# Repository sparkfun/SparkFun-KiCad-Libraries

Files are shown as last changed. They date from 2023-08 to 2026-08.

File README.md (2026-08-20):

SparkFun Electronics KiCad Libraries
====================================

This repository contains the SparkFun KiCad Libraries of commonly used parts. It is a cultivated combination of KiCad stock parts,  SparkFun-unique footprints, and open-source 3D models. The main branch is generally proven out but we apologize in advance if these libraries have errors. Please report any issues! We'll fix them quickly.

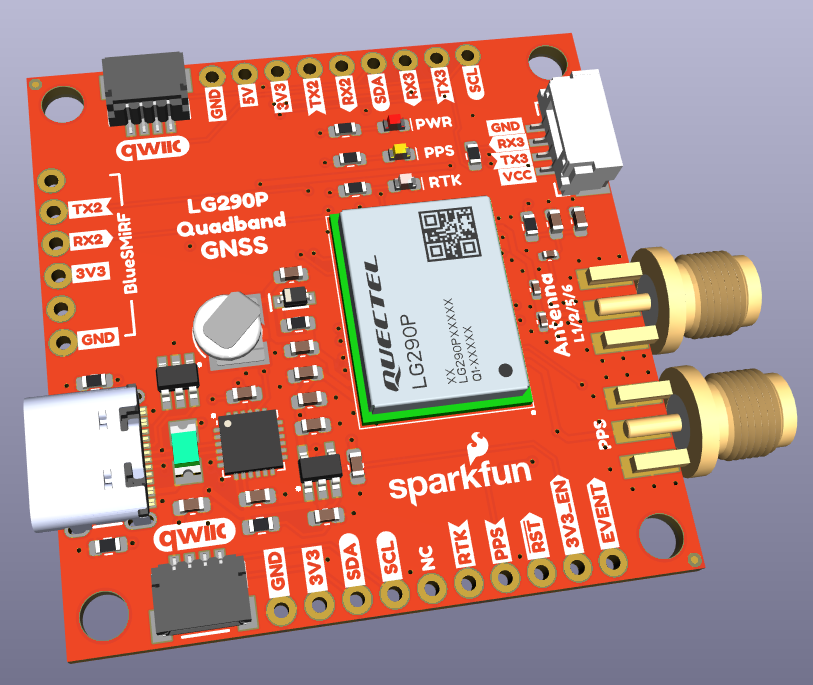
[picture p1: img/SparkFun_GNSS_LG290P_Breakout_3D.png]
SparkFun LG290P Breakout 3D


**Note:** The SparkFun KiCad components contain internal part numbers (**PROD_ID-\***) for ease of manufacture for the SparkFun SMD lines. 

## Theory

KiCad is very good and has a large number of industry specified symbols and footprints. SparkFun has a large number of unique parts and components created since 2002. Rather than converting all previous [SparkFun Eagle libraries](https://github.com/sparkfun/SparkFun-Eagle-Libraries) to KiCad, we are adding new parts to these libraries as we need them for new projects. This gives us the opportunity to clear out old badness, but opens the door to new badness (ie, incorrect footprints) so reader beware!

The SparkFun approach: when a new part needs to be added we decide whether to use a KiCad stock symbol, edit it for use, or create it from scratch. We give preference to the stock KiCad symbol. We give heavy preference to using the original SparkFun footprint, but look at the stock KiCad footprint for inspiration as well. We try to follow the [KiCad Library Conventions](https://klc.kicad.org/) where it makes sense.

Additionally, SparkFun needs to assign various unique manufacturing data (ie, internal part numbers) to parts. To alleviate this, there is a large number of components with an identical symbol each with their own production ID information. For example, capacitors:

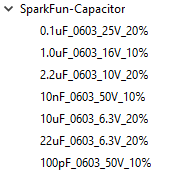
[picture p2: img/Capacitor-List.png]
List of SparkFun capacitors in KiCad


We use the following naming conventions to create our 'bubble gum' parts: 

* [capacity]\_[size]\_[voltage]_[tolerance]
* [resistance]\_[size]\_[wattage optional]_[tolerance optional]
* [inductance]\_[size]\_[max current]
* [led color]\_[size]\_[wavelength optional]

## Installing and using these libraries

* [Installing a release via the KiCad PCM](#installing-a-release-via-the-kicad-pcm)
* [Installing a release from zip file - without the PCM_ Library nickname prefix](#installing-a-release-from-zip-file---without-the-pcm_-library-nickname-prefix)
* [Download the current libraries as a zip file](#download-the-current-libraries-as-a-zip-file)
* [Using Git](#using-git)

Internally, these libraries use an Environmental Variable named `SPARKFUN_KICAD_LIBRARY` to reference the footprints and 3D models. This is converted into `KICAD9_3RD_PARTY` during the release process. The release zip file Assets contain `KICAD9_3RD_PARTY` paths. At SparkFun, we use the library as-is with the original `SPARKFUN_KICAD_LIBRARY` environmental variable paths. Our open-source KiCad designs will contain those same environmental variable paths. If you want to be able to _edit_ existing SparkFun schematics and board designs directly, rather than just make use of our components, you need to manually install a true copy or clone of the library. See [Download the current libraries as a zip file](#download-the-current-libraries-as-a-zip-file) and [Using Git](#using-git) below.

### Installing a release via the KiCad PCM

From the fall of 2025, releases of these libraries are available via the KiCad Plugin and Content Manager (PCM).

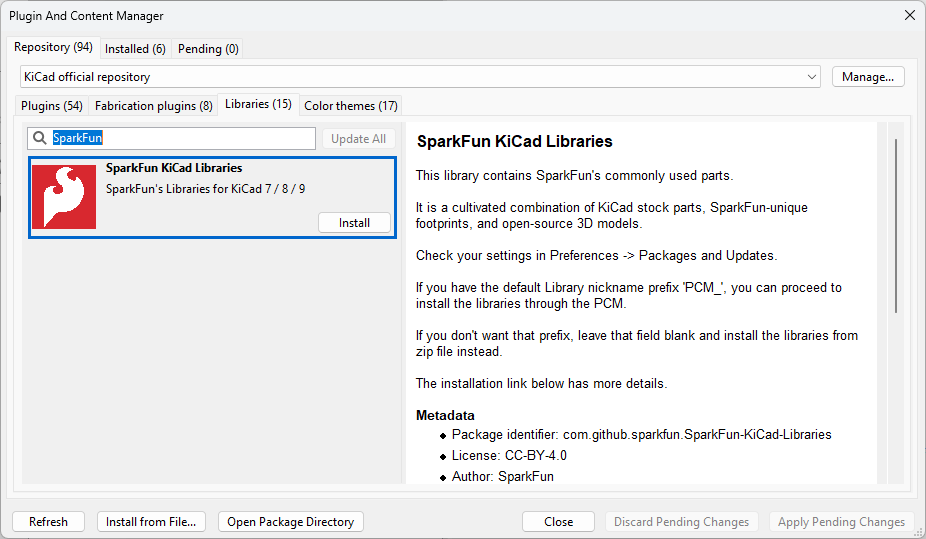
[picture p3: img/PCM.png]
SparkFun KiCad Libraries in the PCM


Open the PCM, select the "Libraries" tab, and type "SparkFun" into the search box. The "Install" button will install the latest release of the libraries.

**If you are using KiCad 10 :** after installing the libraries through the PCM, **close KiCad** and reopen. Only then will the new libraries be visible.

**Note:** this method assumes you have the KiCad Library nickname prefix set to the default of 'PCM_'. If you have cleared the Library nickname prefix, use the [next option](#installing-a-release-from-zip-file---without-the-pcm_-library-nickname-prefix) to install from zip file.

### Installing a release from zip file - without the PCM_ Library nickname prefix

In the KiCad Preferences, you will find settings for "Packages and Updates". The "Library nickname prefix" is applied to any libraries installed through the Plugin and Content Manager (PCM).

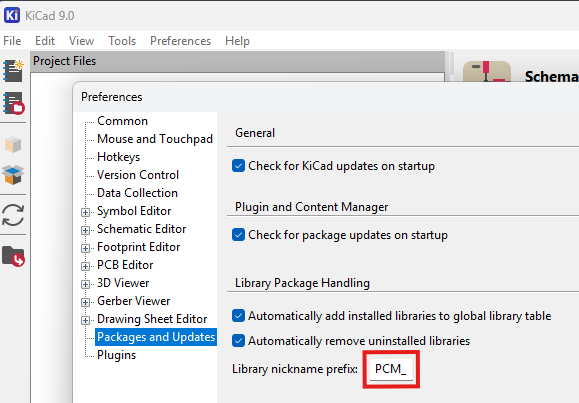
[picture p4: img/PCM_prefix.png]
Library nickname prefix


If you install these libraries though the PCM, the installation assumes the prefix is 'PCM_'. The symbol footprint names will all be prefixed with 'PCM_'. If you have cleared the prefix, you will need to manually install a different version of the libraries without the footprint prefix:

* Navigate to the libraries [Releases page](https://github.com/sparkfun/SparkFun-KiCad-Libraries/releases)
* You will find two zip file "Assets" attached to each release
* Download the **"without-pcm"** zip file
* In the PCM, use the "Install from File..." option to install the zip file

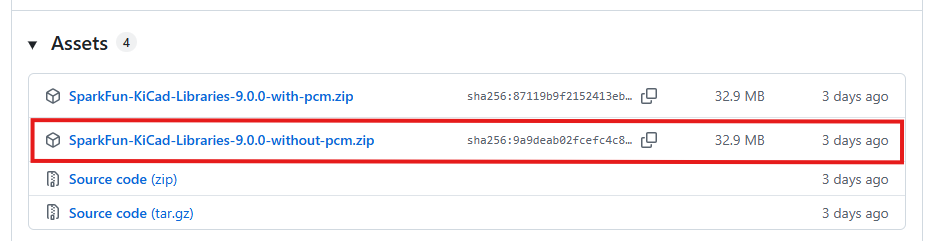
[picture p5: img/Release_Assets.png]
Release Assets


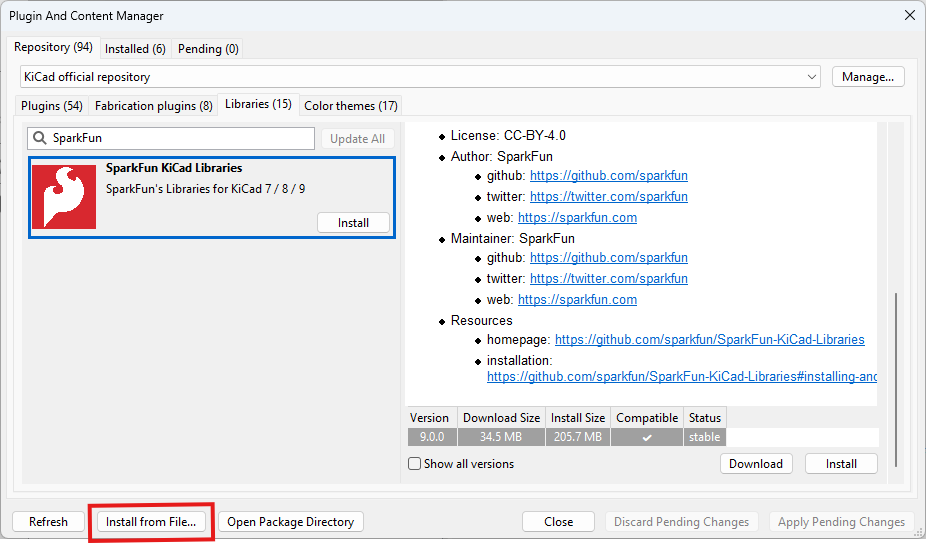
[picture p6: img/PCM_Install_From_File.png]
PCM Install From File


**If you are using KiCad 10 :** after installing the libraries from file, **close KiCad** and reopen. Only then will the new libraries be visible.

If you are changing the Library prefix to use this installation method, we recommend: clearing the prefix, OK the changes, **close KiCad** and reopen before installing the zip file.

### Download the current libraries as a zip file

Instead of waiting for a release, you can download a copy of the libraries at any time by clicking on the big green `<> Code` button above and selecting the `Download ZIP` option. Or, click on the icon below:

Download ZIP (https://github.com/sparkfun/SparkFun-KiCad-Libraries/archive/refs/heads/main.zip "Download ZIP")

Unzip the file somewhere convenient, usually in `Documents`. If needed, change the folder name from `SparkFun-KiCad-Libraries-main` to `SparkFun-KiCad-Libraries`. Open the KiCad **Symbol Editor** and select `Preferences \ Configure Paths`. Add a new Environmental Variable called `SPARKFUN_KICAD_LIBRARY` and set the Path to the `SparkFun-KiCad-Libraries` folder :

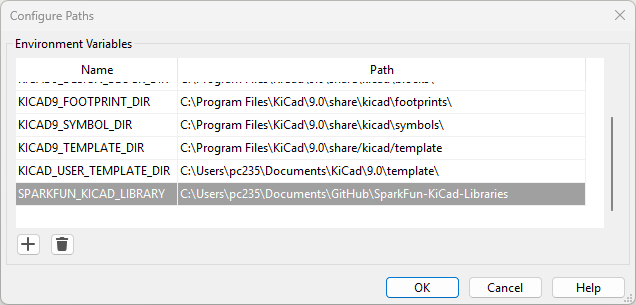
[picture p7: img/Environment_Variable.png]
SPARKFUN_KICAD_LIBRARY Environment Variable


Then select `Preferences \ Manage Symbol Libraries`. Click the folder button to "Add existing library to table". Navigate to the `SparkFun-KiCad-Libraries \ symbols` folder, select all the `SparkFun-.kicad_sym` symbol files and click `Open` :

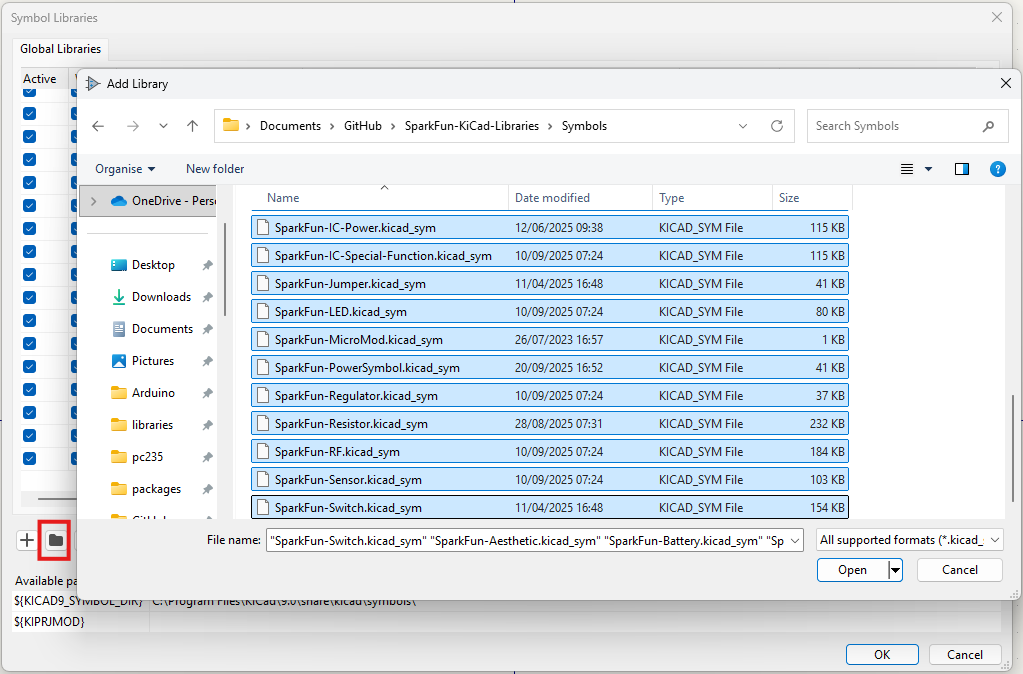
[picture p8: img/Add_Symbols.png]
Adding the symbols


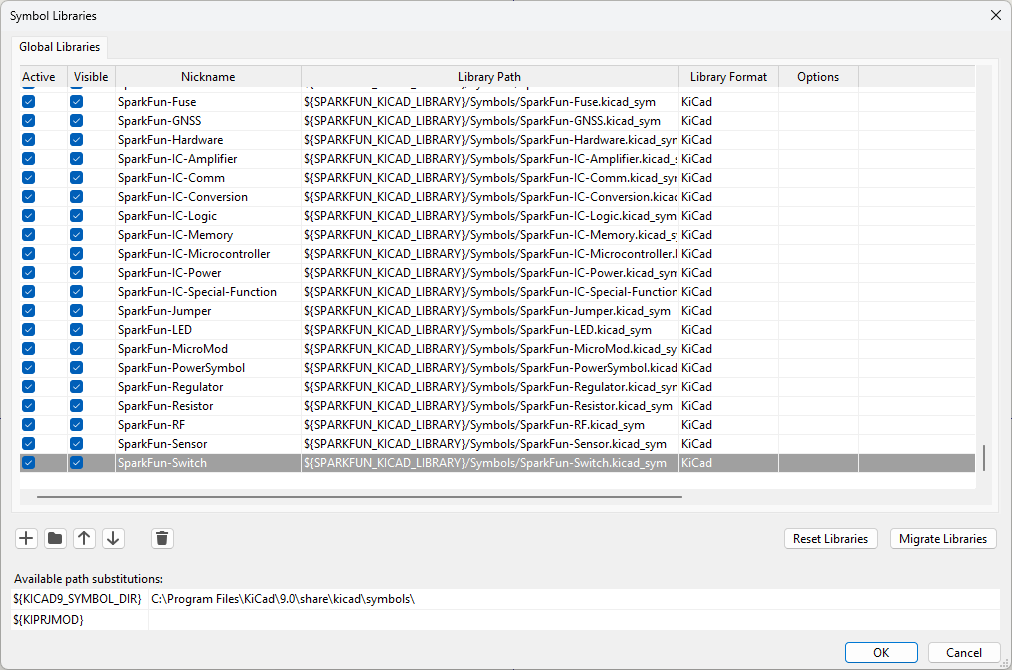
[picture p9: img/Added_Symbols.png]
Added symbols


Then likewise in the **Footprint Editor**, select `Preferences \ Manage Footprint Libraries`. Click the folder button to "Add existing (KiCad folder)". Navigate to the `SparkFun-KiCad-Libraries \ footprints` folder, select everything and click `Select Folder` :

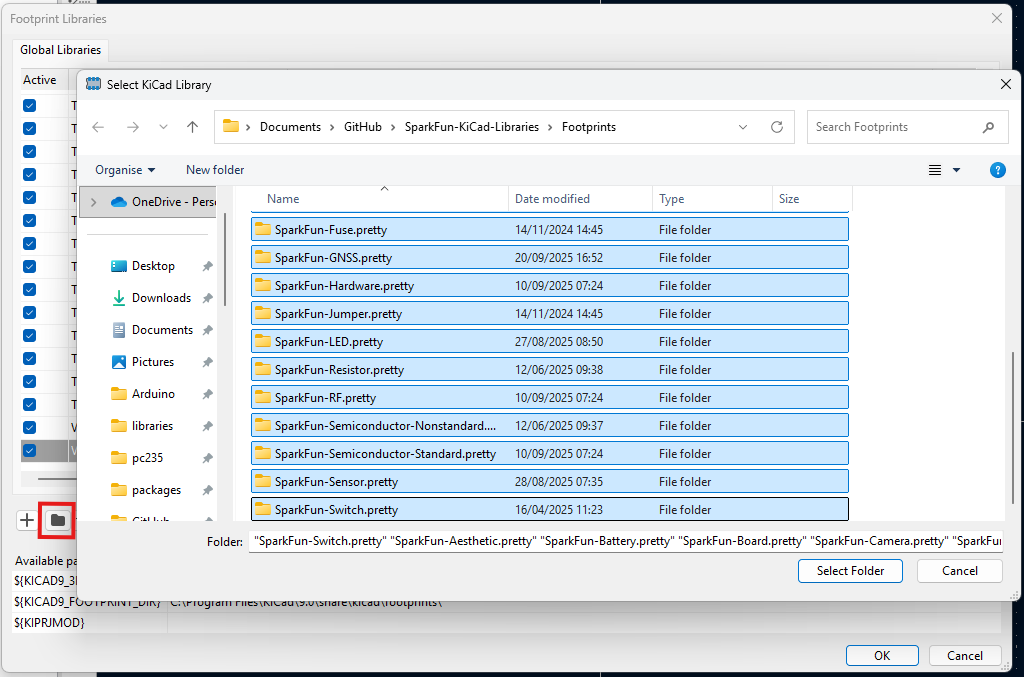
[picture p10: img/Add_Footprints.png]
Adding the footprints


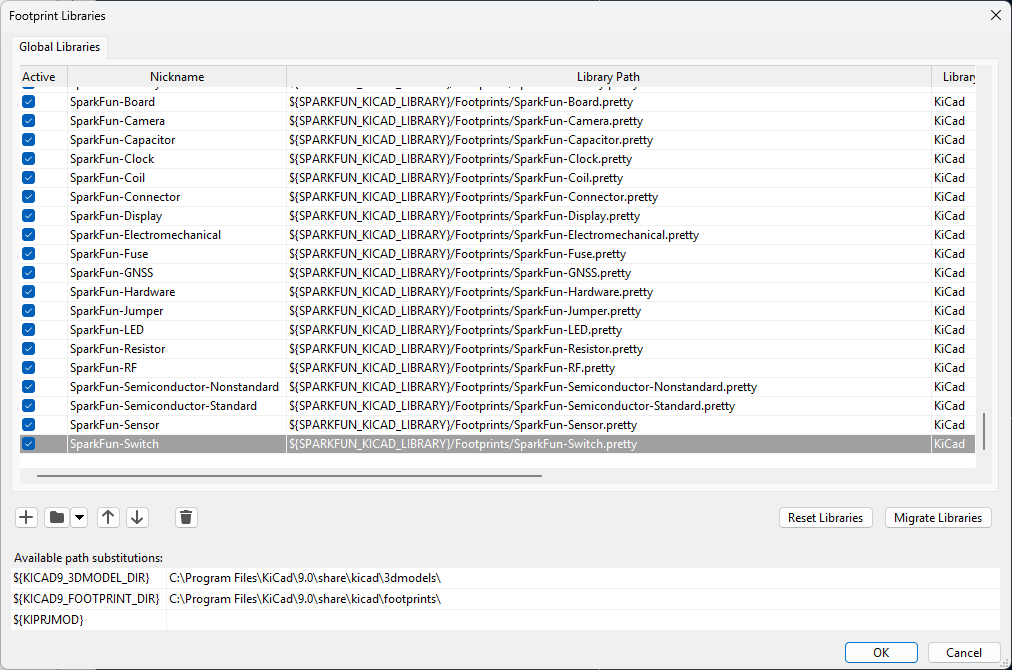
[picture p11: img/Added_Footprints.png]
Added footprints


**If you are using KiCad 10 :** after installing the libraries from zip file, **close KiCad** and reopen. Only then will the new libraries be usable.

### Using Git

If you're familiar with GitHub and Git / [GitHub Desktop](https://desktop.github.com/download/), you can stay completely up to date by cloning this repo.

Again, add the Symbols and Footprints Paths as described in the [previous section](#download-the-current-libraries-as-a-zip-file).

If you use the "Watch All Activity" option above, you will be notified each time we Push changes in the libraries. You can then Pull the changes to stay completely up to date. (It's what we do at SparkFun!)

Contents
-------------------

* [/symbols](https://github.com/sparkfun/SparkFun-KiCad-Libraries/tree/main/symbols) -- Schematic symbols
* [/footprints](https://github.com/sparkfun/SparkFun-KiCad-Libraries/tree/main/footprints) -- PCB footprints
* [/3dmodels](https://github.com/sparkfun/SparkFun-KiCad-Libraries/tree/main/3dmodels) -- 3D models - usually in step format

License
-------------------

This libraries are released under the [Creative Commons Attribution 4.0 International](https://creativecommons.org/licenses/by/4.0/) license. 
**You are welcome to use these libraries for commercial purposes.**
For attribution, we ask that when you begin to sell your device using our footprint, you email us with a link to the product being sold. 
We want bragging rights that we helped (in a very small part) to create your 8th world wonder. 
We would like the opportunity to feature your device on our homepage.

Please consider contributing back to these libraries or others to help the open-source hardware community continue to thrive and grow! 

- Your friends at SparkFun

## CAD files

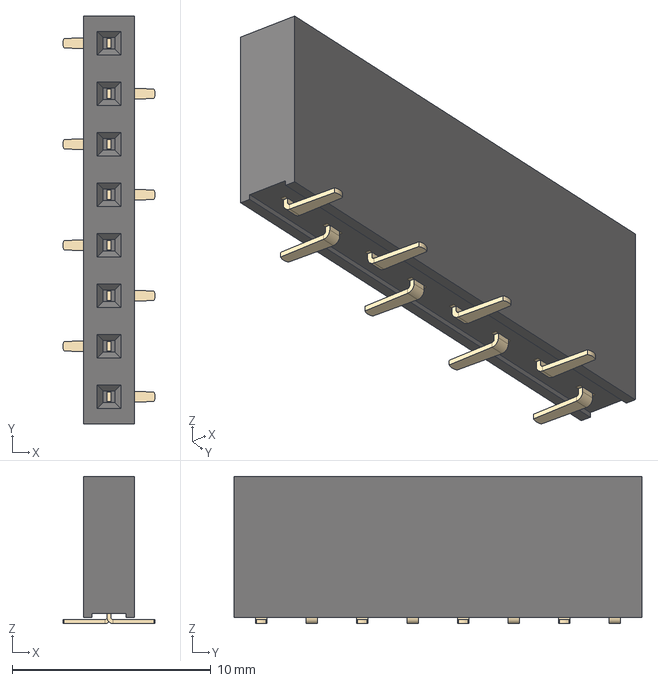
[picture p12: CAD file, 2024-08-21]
Footprints/SparkFun-3D-models/Connector/PinSocket_1x08_P2.54mm_Vertical_SMD_Pin1Left.step
4.64 x 20.5 x 7.40 mm

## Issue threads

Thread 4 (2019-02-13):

Add prefix to footprint package names to avoid conflicts

ianahner, 2019-02-13:
Suggest adding `sparkfun_` or otherwise to avoid conflicts. Currently the `RF.pretty` conflicts with default kicad library `RF.pretty.`

nseidle, 2023-08-09:
Sorry for the late reply! Agreed and added.

Closed 2023-08-09.

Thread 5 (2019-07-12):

Top/bottom and left/right pads have same orientation

jey5nd6, 2019-07-12:
The footprint TQFP32-08 (at least) has all its pads oriented at 0º, but with the top/bottom pads having their height and width swapped from the left/right pads.  This means when Kicad does a Push Pad Properties the "don't modify pads with different orientations" doesn't work.

The pads should have the same widths & heights, but one set should be rotated 90º from the other.

Ref: https://bugs.launchpad.net/kicad/+bug/1836137

nseidle, 2023-08-09:
Sorry for the late reply! We've recently taken a new approach to this library. The TQFP footprint is not yet imported in the latest release. When we do add TQFP32 we'll be sure to base it on KiCad's FP and/or making sure we set the height/width correctly.

Closed 2023-08-09.

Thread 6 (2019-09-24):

SPARKFUN_PRO_MICRO pin assignment is wrong

c-toyama, 2019-09-24:
Pin 14: 11-> 16
Pin 15: 12-> 14
Pin 16: 13-> 15

gnuton, 2020-02-26:
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

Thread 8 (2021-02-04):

alive?

greyltc, 2021-02-04:
Is this maintained anymore? KiCAD is about to switch library formats https://kicad.org/libraries/klc/

nseidle, 2021-02-04:
SparkFun hasn't done much with KiCad recently. Good to know the library structure has changed. I'll mark this repo as archived.

Closed 2021-02-04.

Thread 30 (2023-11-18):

KiCad 7.0 Error: Invalid zero-sized pad pinned to 1µm

Zumili, 2023-11-18:
Hey guys, nice lib, but you still have some errors in 5 of your footprints. KiCad 7 does not like having a pad size of 0 (zero).
The second parameter of the ‘size’ attribute is 0 (such as ‘(size 1.8796 0)’), which must be a minimum of 1µm for KiCad 7.0+

The problematic footprints are:
1X01_OFFSET.kicad_mod
1X40_OFFSET.kicad_mod
2X3_OFFSET.kicad_mod
PSP_CONNECTOR.kicad_mod
STEREOJACK2.5MM_SPECIAL_POGOPINS.kicad_mod

I have attached an ugly, long error log for identifying the footprints with wrong sizes.
Should be a quick fix.

15:59:01: Invalid zero-sized pad pinned to 1µm in
file: SparkFun-KiCad-Libraries-master\Footprints\SparkFun-Connectors.pretty/1X01_OFFSET.kicad_mod
line: 20
offset: 113
15:59:01: Invalid zero-sized pad pinned to 1µm in
file: SparkFun-KiCad-Libraries-master\Footprints\SparkFun-Connectors.pretty/1X40_OFFSET.kicad_mod
line: 175
offset: 112
15:59:01: Invalid zero-sized pad pinned to 1µm in
file: SparkFun-KiCad-Libraries-master\Footprints\SparkFun-Connectors.pretty/1X40_OFFSET.kicad_mod
line: 176
offset: 115
15:59:01: Invalid zero-sized pad pinned to 1µm in
file: SparkFun-KiCad-Libraries-master\Footprints\SparkFun-Connectors.pretty/1X40_OFFSET.kicad_mod
line: 177
offset: 115
15:59:01: Invalid zero-sized pad pinned to 1µm in
file: SparkFun-KiCad-Libraries-master\Footprints\SparkFun-Connectors.pretty/1X40_OFFSET.kicad_mod
line: 178
offset: 115
15:59:01: Invalid zero-sized pad pinned to 1µm in
file: SparkFun-KiCad-Libraries-master\Footprints\SparkFun-Connectors.pretty/1X40_OFFSET.kicad_mod
line: 179
offset: 116
15:59:01: Invalid zero-sized pad pinned to 1µm in
file: SparkFun-KiCad-Libraries-master\Footprints\SparkFun-Connectors.pretty/1X40_OFFSET.kicad_mod
line: 180
offset: 115
15:59:01: Invalid zero-sized pad pinned to 1µm in
file: SparkFun-KiCad-Libraries-master\Footprints\SparkFun-Connectors.pretty/1X40_OFFSET.kicad_mod
line: 181
offset: 116
15:59:01: Invalid zero-sized pad pinned to 1µm in
file: SparkFun-KiCad-Libraries-master\Footprints\SparkFun-Connectors.pretty/1X40_OFFSET.kicad_mod
line: 182
offset: 116
15:59:01: Invalid zero-sized pad pinned to 1µm in
file: SparkFun-KiCad-Libraries-master\Footprints\SparkFun-Connectors.pretty/1X40_OFFSET.kicad_mod
line: 183
offset: 116
15:59:01: Invalid zero-sized pad pinned to 1µm in
file: SparkFun-KiCad-Libraries-master\Footprints\SparkFun-Connectors.pretty/1X40_OFFSET.kicad_mod
line: 184
offset: 117
15:59:01: Invalid zero-sized pad pinned to 1µm in
file: SparkFun-KiCad-Libraries-master\Footprints\SparkFun-Connectors.pretty/1X40_OFFSET.kicad_mod
line: 185
offset: 116
15:59:01: Invalid zero-sized pad pinned to 1µm in
file: SparkFun-KiCad-Libraries-master\Footprints\SparkFun-Connectors.pretty/1X40_OFFSET.kicad_mod
line: 186
offset: 117
15:59:01: Invalid zero-sized pad pinned to 1µm in
file: SparkFun-KiCad-Libraries-master\Footprints\SparkFun-Connectors.pretty/1X40_OFFSET.kicad_mod
line: 187
offset: 117
15:59:01: Invalid zero-sized pad pinned to 1µm in
file: SparkFun-KiCad-Libraries-master\Footprints\SparkFun-Connectors.pretty/1X40_OFFSET.kicad_mod
line: 188
offset: 117
15:59:01: Invalid zero-sized pad pinned to 1µm in
file: SparkFun-KiCad-Libraries-master\Footprints\SparkFun-Connectors.pretty/1X40_OFFSET.kicad_mod
line: 189
offset: 117
15:59:01: Invalid zero-sized pad pinned to 1µm in
file: SparkFun-KiCad-Libraries-master\Footprints\SparkFun-Connectors.pretty/1X40_OFFSET.kicad_mod
line: 190
offset: 116
15:59:01: Invalid zero-sized pad pinned to 1µm in
file: SparkFun-KiCad-Libraries-master\Footprints\SparkFun-Connectors.pretty/1X40_OFFSET.kicad_mod
line: 191
offset: 117
15:59:01: Invalid zero-sized pad pinned to 1µm in
file: SparkFun-KiCad-Libraries-master\Footprints\SparkFun-Connectors.pretty/1X40_OFFSET.kicad_mod
line: 192
offset: 117
15:59:01: Invalid zero-sized pad pinned to 1µm in
file: SparkFun-KiCad-Libraries-master\Footprints\SparkFun-Connectors.pretty/1X40_OFFSET.kicad_mod
line: 193
offset: 117
15:59:01: Invalid zero-sized pad pinned to 1µm in
file: SparkFun-KiCad-Libraries-master\Footprints\SparkFun-Connectors.pretty/1X40_OFFSET.kicad_mod
line: 194
offset: 117
15:59:01: Invalid zero-sized pad pinned to 1µm in
file: SparkFun-KiCad-Libraries-master\Footprints\SparkFun-Connectors.pretty/1X40_OFFSET.kicad_mod
line: 195
offset: 116
15:59:01: Invalid zero-sized pad pinned to 1µm in
file: SparkFun-KiCad-Libraries-master\Footprints\SparkFun-Connectors.pretty/1X40_OFFSET.kicad_mod
line: 196
offset: 117
15:59:01: Invalid zero-sized pad pinned to 1µm in
file: SparkFun-KiCad-Libraries-master\Footprints\SparkFun-Connectors.pretty/1X40_OFFSET.kicad_mod
line: 197
offset: 117
15:59:01: Invalid zero-sized pad pinned to 1µm in
file: SparkFun-KiCad-Libraries-master\Footprints\SparkFun-Connectors.pretty/1X40_OFFSET.kicad_mod
line: 198
offset: 117
15:59:01: Invalid zero-sized pad pinned to 1µm in
file: SparkFun-KiCad-Libraries-master\Footprints\SparkFun-Connectors.pretty/1X40_OFFSET.kicad_mod
line: 199
offset: 117
15:59:01: Invalid zero-sized pad pinned to 1µm in
file: SparkFun-KiCad-Libraries-master\Footprints\SparkFun-Connectors.pretty/1X40_OFFSET.kicad_mod
line: 200
offset: 116
15:59:01: Invalid zero-sized pad pinned to 1µm in
file: SparkFun-KiCad-Libraries-master\Footprints\SparkFun-Connectors.pretty/1X40_OFFSET.kicad_mod
line: 201
offset: 117
15:59:01: Invalid zero-sized pad pinned to 1µm in
file: SparkFun-KiCad-Libraries-master\Footprints\SparkFun-Connectors.pretty/1X40_OFFSET.kicad_mod
line: 202
offset: 117
15:59:01: Invalid zero-sized pad pinned to 1µm in
file: SparkFun-KiCad-Libraries-master\Footprints\SparkFun-Connectors.pretty/1X40_OFFSET.kicad_mod
line: 203
offset: 117
15:59:01: Invalid zero-sized pad pinned to 1µm in
file: SparkFun-KiCad-Libraries-master\Footprints\SparkFun-Connectors.pretty/1X40_OFFSET.kicad_mod
line: 204
offset: 117
15:59:01: Invalid zero-sized pad pinned to 1µm in
file: SparkFun-KiCad-Libraries-master\Footprints\SparkFun-Connectors.pretty/1X40_OFFSET.kicad_mod
line: 205
offset: 116
15:59:01: Invalid zero-sized pad pinned to 1µm in
file: SparkFun-KiCad-Libraries-master\Footprints\SparkFun-Connectors.pretty/1X40_OFFSET.kicad_mod
line: 206
offset: 117
15:59:01: Invalid zero-sized pad pinned to 1µm in
file: SparkFun-KiCad-Libraries-master\Footprints\SparkFun-Connectors.pretty/1X40_OFFSET.kicad_mod
line: 207
offset: 117
15:59:01: Invalid zero-sized pad pinned to 1µm in
file: SparkFun-KiCad-Libraries-master\Footprints\SparkFun-Connectors.pretty/1X40_OFFSET.kicad_mod
line: 208
offset: 117
15:59:01: Invalid zero-sized pad pinned to 1µm in
file: SparkFun-KiCad-Libraries-master\Footprints\SparkFun-Connectors.pretty/1X40_OFFSET.kicad_mod
line: 209
offset: 117
15:59:01: Invalid zero-sized pad pinned to 1µm in
file: SparkFun-KiCad-Libraries-master\Footprints\SparkFun-Connectors.pretty/1X40_OFFSET.kicad_mod
line: 210
offset: 116
15:59:01: Invalid zero-sized pad pinned to 1µm in
file: SparkFun-KiCad-Libraries-master\Footprints\SparkFun-Connectors.pretty/1X40_OFFSET.kicad_mod
line: 211
offset: 117
15:59:01: Invalid zero-sized pad pinned to 1µm in
file: SparkFun-KiCad-Libraries-master\Footprints\SparkFun-Connectors.pretty/1X40_OFFSET.kicad_mod
line: 212
offset: 117
15:59:01: Invalid zero-sized pad pinned to 1µm in
file: SparkFun-KiCad-Libraries-master\Footprints\SparkFun-Connectors.pretty/1X40_OFFSET.kicad_mod
line: 213
offset: 117
15:59:01: Invalid zero-sized pad pinned to 1µm in
file: SparkFun-KiCad-Libraries-master\Footprints\SparkFun-Connectors.pretty/1X40_OFFSET.kicad_mod
line: 214
offset: 117
15:59:01: Invalid zero-sized pad pinned to 1µm in
file: SparkFun-KiCad-Libraries-master\Footprints\SparkFun-Connectors.pretty/2X3_OFFSET.kicad_mod
line: 41
offset: 120
15:59:01: Invalid zero-sized pad pinned to 1µm in
file: SparkFun-KiCad-Libraries-master\Footprints\SparkFun-Connectors.pretty/2X3_OFFSET.kicad_mod
line: 42
offset: 121
15:59:01: Invalid zero-sized pad pinned to 1µm in
file: SparkFun-KiCad-Libraries-master\Footprints\SparkFun-Connectors.pretty/2X3_OFFSET.kicad_mod
line: 43
offset: 116
15:59:01: Invalid zero-sized pad pinned to 1µm in
file: SparkFun-KiCad-Libraries-master\Footprints\SparkFun-Connectors.pretty/2X3_OFFSET.kicad_mod
line: 44
offset: 117
15:59:01: Invalid zero-sized pad pinned to 1µm in
file: SparkFun-KiCad-Libraries-master\Footprints\SparkFun-Connectors.pretty/2X3_OFFSET.kicad_mod
line: 45
offset: 119
15:59:01: Invalid zero-sized pad pinned to 1µm in
file: SparkFun-KiCad-Libraries-master\Footprints\SparkFun-Connectors.pretty/2X3_OFFSET.kicad_mod
line: 46
offset: 120
15:59:01: Invalid zero-sized pad pinned to 1µm in
file: SparkFun-KiCad-Libraries-master\Footprints\SparkFun-Connectors.pretty/PSP_CONNECTOR.kicad_mod
line: 12
offset: 32
15:59:01: Invalid zero-sized pad pinned to 1µm in
file: SparkFun-KiCad-Libraries-master\Footprints\SparkFun-Connectors.pretty/STEREOJACK2.5MM_SPECIAL_POGOPINS.kicad_mod
line: 21
offset: 128
15:59:01: Invalid zero-sized pad pinned to 1µm in
file: SparkFun-KiCad-Libraries-master\Footprints\SparkFun-Connectors.pretty/STEREOJACK2.5MM_SPECIAL_POGOPINS.kicad_mod
line: 22
offset: 129
15:59:01: Invalid zero-sized pad pinned to 1µm in
file: SparkFun-KiCad-Libraries-master\Footprints\SparkFun-Connectors.pretty/STEREOJACK2.5MM_SPECIAL_POGOPINS.kicad_mod
line: 23
offset: 123
15:59:01: Invalid zero-sized pad pinned to 1µm in
file: SparkFun-KiCad-Libraries-master\Footprints\SparkFun-Connectors.pretty/STEREOJACK2.5MM_SPECIAL_POGOPINS.kicad_mod
line: 24
offset: 121

nseidle, 2023-11-19:
You are using 'SparkFun-Connectors" which is no longer in the main branch (master doesn't exist any longer). We deprecated our old footprints a few months ago - please see the [readme](https://github.com/sparkfun/SparkFun-KiCad-Libraries/tree/main). The new one is [SparkFun-Connector.pretty](https://github.com/sparkfun/SparkFun-KiCad-Libraries/tree/main/Footprints/SparkFun-Connector.pretty) and is significantly smaller than the pre v7 version, but should be much more curated.

Closed 2023-11-19.

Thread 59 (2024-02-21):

unable to install SparkFun library to KiCad  7.0.10

Paul-G0, 2024-02-21:
running latest version of Raspberry Pi os on Raspberry Pi 5 8Gb
Discovered a problem, and was advised to upgrade KiCad, which I did via Flatpak, to see if solved.
Now version 7.0.10

2 methods, but essentially still the same problem:

1. downloaded  .zip file, copied to /usr/share/kicad/3rd_party/sparkfun/sparkfun_kicad_libraries, unzipped.
 I then set global variables in KiCad to point at the Footprint & Symbol libraries.
  Looking at both Symbol and Footprint libraries, I see only one of the two, it's marked as sparkfun, and it's not
 expandable to show individual parts. To ensure they were correct, I had  navigated to the directories I created then
 did   'pwd' and copy/pasted that.

2. used the plugin & content manager, selected libraries tab, install from file, navigated to original sparkfun.zip,
   selected it. after a few seconds I get the error message "Archive does not contain a valid metadata .json file"

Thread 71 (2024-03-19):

New v8 Search / Filter box limits part discovery

nseidle, 2024-03-19:
In v7, the searching the word 'SparkFun Push' allowed discovery of all SparkFun available push button switches because the search box included the file names ("SparkFun-Switch.pretty" was included). In v8, the file names are not searched, so only the FPs that have the word sparkfun explicitly in the keyword/description box is included in the search results.

I put 'SparkFun' in front of nearly all my searches to remove the kicad default libs, but this is hindering v8 use. This is a problem for symbol search as well.

Possible solutions:

* Add the keyword SparkFun to all FPs and symbols.
* Make users not import/use default KiCad libs/symbols, just search without the word SparkFun
* Allow import of default libraries, make user wade through

@PaulZC I'm leaning towards adding the keyword but it feels brute force to me. Have you got any ideas?

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

And symbols as well:
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

PaulZC, 2024-03-19:
@nseidle : are you on 8.0.0 or 8.0.1? I _think_ it is behaving correctly for me in 8.0.1? But my libraries are still in v7 format...

nseidle, 2024-03-19:
Interesting. I'm on 8.0.1. I haven't converted or re-saved any lib (still in v7). I just did the standard adding of KiCad libraries to the end of the defaults:

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

How are you installing things?

PaulZC, 2024-03-20:
Here's what I see in 8.0.1:

In the schematic editor:

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

In the symbol editor:

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

Ah. Interesting. Searching for "sparkfun" doesn't find the PowerSymbol symbols. With no filter, it's there:

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

Add "sparkfun" as the filter and it's not there:

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

Everything goes weirdly non-alphabetic too:

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

PaulZC, 2024-03-20:
MicroMod is missing too. I think this only applies to MicroMod and PowerSymbols? Ah, MicroMod doesn't contain any symbols.

How am I installing things? With Preferences \ Manage Symbol Libraries. I use the folder button to add them all in one go:

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

Same for the footprint editor. Preferences \ Manage Footprint Libraries and the folder button:

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

Oh... Is it because PowerSymbols doesn't reference any SparkFun footprints? If it did, it would find them...

I'm with you on adding SparkFun to the Keywords. Sounds like a job for Reg Ex... Watch this space...

PaulZC, 2024-03-20:
OK. That's better:

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

PR is [here](https://github.com/sparkfun/SparkFun-KiCad-Libraries/pull/72)

nseidle, 2024-03-20:
I added keywords to the footprints.

Closed 2024-03-20.

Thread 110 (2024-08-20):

Add courtyards around 0.1" PTH header footprints

sfe-SparkFro, 2024-08-20:
First off, all footprints should really have a courtyard to ensure DRC catches any accidentally overlapping parts.

Second, if a user wants to solder headers onto a board, there needs to be clearance for the headers, which are 0.1" wide. It's easy to forget this when designing a tight layout, such as the instance below (the outer 2x 0402 footprints would interfere with a header)

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

Just need to add courtyard rectangles 0.1" wide like so:

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

nseidle, 2024-08-28:
How about a much closer courtyard that would avoid collision with the standoff but still prevent components?

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

Also, I've added screws and nuts for 4-40 and M3.

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

SFE-Brudnerd, 2024-08-28:
My only argument against a tighter courtyard like what Nate suggests is if a user desires to populate with 0.1" headers then the black plastic could interfere.

nseidle, 2024-08-28:
Good point. We could add the outline to layer User1:

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

It will pass collision errors but make the designer aware of the possible issue.

Good enough?

SFE-Brudnerd, 2024-08-28:
WFM!

PaulZC, 2024-08-28:
My vote would be F.Fab. I've been using User.1 for milling. I submitted a PR recently to move all User1 text to F.Fab. I'd prefer not to start using it again for things like this...

PaulZC, 2024-08-28:
https://github.com/sparkfun/SparkFun-KiCad-Libraries/pull/106#issuecomment-2254102679

nseidle, 2024-08-28:
Talking this over with @sfe-SparkFro, we elected to keep the rectangular courtyard so that it does throw an error, and then the designer can exclude the error if they're ok with the collision.

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

Rectangular courtyards will land in a minute on main.

Closed 2024-08-28.

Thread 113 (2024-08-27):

Change PTH pads to "F.Cu, B.Cu, and connected layers"

sfe-SparkFro, 2024-08-27:
I believe all our footprints with PTH pads have the "Copper layers" setting set to "All copper layers" like so:

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

However I would like to suggest changing them all to "F.Cu, B.Cu, and connected layers"

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

This gives a lot more clearance between adjacent pads on inner layers, which is actually important for a board I'm working on with a lot of headers in the middle of the board. Below, the left pair of pads is set to "F.Cu, B.Cu, and connected layers" and the right pair are set to "All copper layers". With default track and DRC settings, I can route up to 3 tracks between the left pair, but only 1 track between the right pair:

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

I think this change should be made to all PTH pads in our library. I don't see any downside to it other than taking time to update them all. But also open to discussion from others!

nseidle, 2024-08-27:
WFM! Please make the changes.

Closed 2024-10-30.

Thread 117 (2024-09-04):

Part request - PRT-13054

owlyowl, 2024-09-04:
Hi I was wondering if it's possible to add this to the library please?

nseidle, 2024-09-04:
Sure! Merged now. You can find it under SparkFun-Connectors/Raspberry_Pi* But please check my work. I haven't used this part in a design yet so let me know if you see any issues. It's largely just a combination of built-in KiCad parts.

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

owlyowl, 2024-09-04:
Hi Nathan!
Thanks so much!!

On Thu, 5 Sept 2024, 5:22 am Nathan Seidle, ***@***.***>
wrote:

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

Closed 2024-09-04.

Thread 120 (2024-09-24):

Pin Header Footprints, Locked Versions Missing

thestumbler, 2024-09-24:
It looks like all the staggered-hole pin header footprints from the original SparkFun Eagle libraries, as written about in this [tutorial post](https://www.sparkfun.com/tutorials/114) by @lewispg228  way back in 2008, didn't survive the transition to KiCad libraries, with the lone exception of the 1x03 pin header. Any particular reason these were dropped?

I discovered you can open the old Eagle libraries in KiCad and a wide assortment of staggered-hole pin header footprints are available that way.

This is just an observation.  But assuming it wasn't an intentional decision to drop these footprints when you moved forward to KiCad libraries, I would say it is a suggestion as well.

nseidle, 2024-09-24:
Hello!

> Any particular reason these were dropped?

I should come up with a really good conspiracy theory, but the real answer is that we are moving over FPs only when we use them (it's work to clean them up and get them to our KiCad standards). And I just haven't designed anything with locking yet.

But, I went ahead and added 30 down to 3 of the locking FP (does 2 lock? 1 is silly), and 20 down to 3 of symbols. They should be merged into main. Let me know if I messed anything up.

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

thestumbler, 2024-09-25:
Sounds good to me. BTW, as I was looking at these last night, I was struck by the fact that pin 1 of these footprints, indeed all pins, are not on the centerline of the connector pattern. That is by design, of course, the very definition of staggered. However, I might suggest that having pin 1 only not staggered could be a prudent thing to do without compromising the reason behind  staggering the pins in the first place.

As is, the placement origin of the part is not the centerline of the pin 1 hole. One could be tempted to place the part on the board 5 mils offset from its intended location. I could certainly see myself making that blunder. In 99% of the cases that probably won't matter at all.

So, if you whipped out all of these using a script, I might suggest considering such a modification (pin 1 doesn't get staggered). If you did all these by hand, I'd say leave it alone.

Also I'll note that the original library had both 1x and 2x pin headers with staggering. Again, if you made these by script, I'd think making the corresponding 2x footprints also. Otherwise no big deal. It's trivial to take the 1x footprints and whip up a corresponding 2x as needed.

Thanks for taking care of of this so quickly.

nseidle, 2024-09-25:
Me, [scripts](https://xkcd.com/1319/)? It was manual but not bad.

I totally agree pin 1 should be on grid to aid locating.

2x pin headers will be left for a PR, or when somebody here needs them.

nseidle, 2024-09-25:
Pin 1 now on grid. Good idea! Again, let me know if anything looks odd.

Closed 2024-09-25.

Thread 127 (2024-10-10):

Add voltage regulator parameters

sfe-SparkFro, 2024-10-10:
We commonly add the voltage and current rating of regulators in schematics as external text like so:

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

I think it would make sense to add those ratings to the regulators themselves, similar to the capacitors in this screenshot.

PaulZC, 2024-10-11:
It's a good suggestion... I included similar on the DC-DC converters:

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

nseidle, 2024-10-16:
I approve of all this. I haven't gotten a chance to get to it, so if you PR it, I'll make it so.

Closed 2024-11-13.

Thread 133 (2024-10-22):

Barrel PTH slot footprint is wrong

sfe-SparkFro, 2024-10-22:
I ordered some protos with the current slot footprint, and the barrel connector is much more difficult to insert than the original Eagle footprint. It _can_ be inserted, but it's a lot more difficult. Not sure whether this change was intentional, but given variations in PCB manufacturing tolerances, the footprint should be reverted back to how the Eagle footprint was designed.

I can do this, just documenting it here.

Closed 2024-10-25.

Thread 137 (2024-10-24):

Soldermask expansion/margin overrides

sfe-SparkFro, 2024-10-24:
A lot of footprints have a manual override for the soldermask. For example, most of our PTH pads have an expansion of 0.1016mm (0.004", which is uncomfortably close when I have a copper clearance of 0.005"):

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

However other footprints have no override, such as our capacitors:

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

In general, what should the override be set to? And does it depend on the footprint?

Personally, I think all footprints should not override the soldermask expansion, it should instead be specified in the board setup like so:

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

If that's what we decide, then we'll need to remove the override from all footprints.

nseidle, 2024-10-25:
@edspark showed me the error in some of the FPC footprints (that have overrides but should not).

IMO, FPs should *not* have overrides and we should rely on a global expansion if needed.

If you've got a recommended solution, I'm likely for it.

Closed 2024-10-30.

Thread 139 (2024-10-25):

Add SparkFun SEN-15242

dankamongmen, 2024-10-25:
It would be great to have the [SEN-15242 NAU7802](https://www.sparkfun.com/products/15242) in the parts collection, suitable for use with KiCad 8. I can perhaps do this if there's no one upstream who wants to handle it (assuming I haven't just overlooked it).

dankamongmen, 2024-10-25:
for my purposes, i'd like the schematic element ("kicad_sym") and the footprint ("kicad_mod").

i am just a dumb computer scientist, and eight, and am learning kicad as i go along--but i will definitely try! the NAU7802 itself is available (i've imported it from Ultra Librarian) so i ought be able to use that as a basis for the schematic element.

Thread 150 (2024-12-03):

WDFN-8_6x5mm-SkinnyCenterPad solder mask on center pad does not respect mask expansion rule

sfe-SparkFro, 2024-12-03:
I have a board with relatively tight settings:

* Solder mask expansion - 0.05mm (0.002in)
* Zone clearance - 0.127mm (0.005in)

The center pad and its solder mask are defined as polygons, which causes the mask to overlapping with the GND zone in the corners:

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

The center pad should defined as a pad, so the board's mask expansion rule is respected.

nseidle, 2024-12-05:
Thanks for the fix!

Closed 2024-12-05.

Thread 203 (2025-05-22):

The library is not compatible with kiCad8

hossamemad5566, 2025-05-22:
please provide me with one which is compatible with it

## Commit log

2017-11-30 Adding graphics to doc
    [_saved_boostboard1.sch]
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2023-07-26 Moving previously ported libraries to subfolder
    [_saved_boostboard1.sch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]
2023-07-26 Fix LED FPs
2023-07-26 Fix slotted holes on USB C and power jacks
2023-07-27 Add Connector I2C_01x04. Replaces Eagle I2C_STANDARD
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2023-07-28 Fix pin orde of 3 way jumper.
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2023-08-08 Decrease soldermask on USB C and jumper to avoid DRC warnings.
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2023-09-06 Fix ordering instructions - rename footprint; move instructions to User.1
2023-09-18 Fix prod ID to use new RED LED
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2023-11-08 Fix visible name on battery
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2023-12-06 Fix LED symbols
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2023-12-12 Fix courtyard thickness on footprints
2023-12-29 Flip the RGB footprint
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2024-01-04 Fix pad names on capacitor FP
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2024-01-12 Correct DET pin on microSD friction
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2024-01-18 Fix courtyard on S3 Mini footprint.
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2024-01-22 Update FPD_12_0.5MM - add missing F.Paste
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2024-01-22 Make fixes from PR review doc
    - Add Conn 15pos FP
    - Add Barrel jack datasheet and PROD_ID
    - Add Screw terminal datasheet and PROD_ID
    - Add JZC relay value and prod ID. Update symbol.
    - Move JZC Reference Designator to F.Fab
    - Add T90 PROD_ID
    - Add max current ratings, coil voltages, etc to all the relays symbols.
    - Remove PDIP16 FP
    - Updated existing symbols to use DIP16
    - Fix DIP16 FP
    - Fix DIP4 FP
    - Add TLP627-4 PROD ID
    - Add TLP627 PROD ID
    - Fix SMDIP4 FP
    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
2024-02-13 Correct Qwiic connector footprints in symbols
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2024-02-16 Update BP2G1+ Bypass1/2 footprints - no more errors or warnings!
2024-02-16 Replace PROD ID on 330 ohm 0402 with 470 ohm 0402
2024-02-16 Fix FP on USB connector. Fix tolerance on cap.
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2024-02-22 updating fp to sfe standards
    FOOTPRINT
    -ref center aligned, moved to correct F.Fab layer, width/hieght/thickness corrected.
    -line wide of silk to .15mm
    -removed "${REFERENCE}" text object
    -added courtyard
    -updated pad size/location to match datasheet
    -renamed to "Trimpot_SMD_3.0x3.0mm"
    SYMBOL
    -corrected reference des to just "R1"
    -made the "k" in "10k" lower-case
    -added datasheet link
    -name changed to "Trimpot_10k_SMD_3.0x3.0mm"
    -all pads spoke angles changed to "0"
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2024-02-28 Fix pins on SMD push buttons
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2024-03-20 Fix off grid pin
2024-03-20 Fix Ref/Val on PTH connectors. Fix castellated.
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2024-04-05 corrected voltage and current on PCH mosfet
2024-04-06 Fix prod ID on 20k 0603 resistor. Move description text on all caps/res.
2024-04-08 8-POWERDFN footprint corrections
    -switched drain connection pad from multiple pads (5/6/7) to a single complex shaped pad (5).
    -moved reference designator to fab layer
    -corrected reference designator text size and thickness
2024-04-12 PowerFLAT package mods
    -Moved package into SparkFun-Semiconductor-Standard
    -Renamed the package for this Power MOSFET. It is more correctly named "ST_PowerFLAT-8L_3x3mm_P0.065mm". This follows the naming of the other PowerFLAT package found in the larger KiCad Libraries (found in Package_SON).
    -repositioned ref and value text to above & below
    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
2024-04-29 Move pwr/gnd pins to left side
    -and tightened up spacing a bit, to make it a smaller symbol
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2024-06-19 corrected antenna rule area (aka "keepout")
    -it now blocks out copper on inner layers
2024-06-25 3d model added for FPC-24
    [FPC-24-Amphenol-SFV24R-1STE1HLF.step]
2024-06-27 Mount pads are now graphical shapes
    -Mount pads are now graphical shapes, and this will help avoid DRC errors
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2024-07-01 Fixes solder mask aperture
    * Removes the solder mask expansion in favor of 1:1 ratio of solder pad to solder mask
    * This removes the many many DRC errors that overlapping solder mask polygons create.
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2024-07-18 Fix SOT-490 Courtyard
    Current layer is Margin, meaning you can't route out from it
2024-07-18 Fix APS6404L footprint
    Also connect pin 9 to GND
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2024-07-22 Correct SMA Edge and u.FL connectors
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2024-07-22 Fix MAX17048 GND Direction
    Was set as Power Output, resulting in ERC error. Should be Power Input
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2024-07-27 Correct footprint for 100uF_6.6x6.6_25V_20% (Panasonic_D)
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2024-07-27 Fix Panasonic_C footprint : correct origin, add courtyard
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2024-08-05 Fix PROD_IDs on SEN55 connector and outline
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2024-08-05 Fix UDFN-8 footprint name
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2024-08-13 Fix Z on Qwiic connector. Add 3D models.
2024-08-13 Add 3mm LED lightpost
    [934SA.STEP]
2024-08-14 3D model: Fix JST
    [JST - PH - SMD (R) - 2Pin - 2.00mm Black.step, JST - PH - SMD (R) - 2Pin - 2.00mm.stp]
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2024-08-16 Move caps/res from external lib to SparkFun lib.
    [C_0201_0603Metric.step, C_0402_1005Metric.step, C_0603_1608Metric.step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]
2024-08-16 3D model: Add trimpot
    [Trimpot_3313J.step]
2024-08-16 3D model: Add 5.2mm buttons
    [Tactile_Switch_5.2x5.2mm_h1.9mm.STEP, Tactile_Switch_5.2x5.2mm_h2.5mm.step]
2024-08-17 3D models: Add SMD Buttons
    [KMR421GULCLFS.step, PinHeader_1x06_P2.54mm_Horizontal_SMD_Right.step, Push_SMD_4.6x2.8mm.step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]
2024-08-20 Change 24-pin FPC model
    [FPC-24-Amphenol-SFV24R-1STE1HLF.step]
2024-08-21 3D models: Add crystals
    [Crystal_SMD_2.0x1.6mm.STEP, Crystal_SMD_3.2x2.5mm.STEP]
2024-08-21 Fix height of 3528 cap
    [CP_EIA-3528-21_Kemet-B.step, CP_EIA-3528-21_Vishay-B.step]
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2024-08-22 Update microSD. Rename connector models.
    [112J-TDAR-R01.stp, 934SA.STEP, BM04B-SRSS-TB.STEP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]
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2024-08-26 Add 4-40 screw and 4-40/M3 nuts for standoff modeling
    [Nut_4-40.step, Nut_M3.step, Screw_4-40.step]
2024-08-26 Fix resistor models
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2024-08-28 Add screw and nut for M3 and 4-40.
    [Screw_M3.step]
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2024-08-29 Fix background on schematic symbol
2024-08-30 Fix 8 pin SMD pin1right connector
    [PinSocket_1x08_P2.54mm_Vertical_SMD_Pin1Right.step]
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2024-09-05 Add USB ESD for host. Add audio PCM, low noise reg, STM32.
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2024-09-17 Add OLED, reverse mount green LED, resistors, caps
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2024-10-03 Add 3D models for 14 and 12pin JST
    [JST_SM12B-SRSS-TB.step, JST_SM14B-SRSS-TB.STEP]
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2024-10-08 Fix pad number on rear mount RGB
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2024-10-09 Fix PowerVFDFN-13 reference and step file
    [PowerVFDFN-13.stp]
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2024-10-15 Correct AP7361C 1A regulators
2024-10-15 Add 3D model for AP7361C (U-DFN3030-8 Type E)
    [DFN-8_3x3mm_P0.65mm.step]
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2024-10-24 Correct PTH barrel jack
    [Power_Jack_PTH.step]
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2024-10-24 Add 16V 2.5A/5.0A fuse
    Also add 3D model for 1812 fuse footprint
    [Fuse_1812_4532Metric.step]
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2024-10-24 Add 0806 polarized inductor
    Special inductor manufactured by Abracon for the RP2350. Bourns datasheet is a placeholder for now
    [Inductor_0806.step]
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2024-11-15 Change silk on U.FL to avoid mounting confusion
    Some U.FL connectors have a trim corner in other corners that the silk shown.
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2024-11-15 Fix override on JST 4 2mm
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2024-11-18 Fix silk and pinout on nav switch
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2024-11-21 Add 3D models
    - Add 1.3" OLED model (folded over)
    - Add Generic ESP32-MINI model
    - Add RP-SMA model
    - Associate with library footprints
    [ESP32-MINI.step, RP-SMA-Edge.step, UG-2864KSWLG01.step]
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2024-11-29 Correct the GNSS socket pin mirroring
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2024-12-03 Add RM2
    Normal and tight footprints
    [RM2.STEP]
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2024-12-05 Rework relays. Add new variants.
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2024-12-06 Fixes three way jumpers after last push
    * Two of the three way jumpers shared the same pin number and so shared
    the same net/electrical connection. This simply fixes the third pad to
    be pin three.
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2025-01-09 Add various footprints and symbols
    Parts associated with moving the USB RFID design to KiCad
    - Add polarized version of 0603 capacitor footprint
    - Add 2mm pitch SMD headers for ID-Innovations modules
    - Add mechanical layout footprint for arranging headers in ID-Innovations configuration
    - Add SMT Buzzer
2025-01-09 Add various parts
    Add existing PFET.
    Add existing SMD Barrel Jack.
    Add 3-pin Vertical JST 1mm.
    Add existing 1x08 and 1x10 SMD headers.
    Add 1x22 FPC 0.5mm.
    [BG125-06-A-2-1-0420-N-C.stp, BG125-08-A-2-1-0420-N-C.stp, BG125-10-A-2-1-0420-N-C.stp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]
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2025-01-13 Correct pad names on SMA footprint for D_Schottky_3A_40V_0.55V
2025-01-13 Replace BH292 3D model with Paul's OpenSCAD version
    [BH292.step, BH292_MNC.step]
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2025-01-16 Add 3D model for RPi passthrough connector - generated with OpenSCAD
    [Raspberry_Pi_Passthrough_Header.step]
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2025-01-16 Add AVR ISP. Add 1x4 RA SMD male header.
    [1x04_RA_SMD.step]
2025-01-20 Correct hole dia. for 2x10 2mm female socket
    Alignment pegs are rectangular: 1.1 x 0.8mm. Hole dia. is 1.5mm
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2025-01-20 Add CC BY-ND models for 2x10 2mm GNSS header and socket
    [BF030-20A-B1-0360-0277-0600-LB.stp, BF100-20-A-D-1-0640-L-C.stp]
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2025-01-21 2x10 : update models; add Cu layers for mask expansion
    [BF030-20A-B1-0360-0277-0600-LB.stp, BF100-20-A-D-1-0640-L-C.stp]
2025-01-21 Fix 3D model on LG290P
    [LG290P.step]
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2025-01-22 Fix path to LG290P footprint
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2025-01-23 Fix link to LG290P footprint
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2025-01-28 Add hide-able SD card 3D model to microSD socket
    [microSD_Card.step]
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2025-01-30 Rename step files for 2x10 2.0mm header and socket
    [2x10_2.0mm_Header_SMD_Peg-1.0mm.stp, 2x10_2.0mm_Socket_SMD_Peg-1.1x0.8mm.stp]
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2025-01-31 Correct Pin 1 marker on RPi passthrough bottom-entry
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2025-02-14 Add missing step. Add silk to FP.
    [SOT-490.step]
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2025-02-14 Update based on feedback.
    6 pin STEP gen via Fusion
    8 pin STEP gen
    10 pin STEP gen
    Color in CF20221V0R0-NH STEP
    DCJ STEP gen
    Update 1x06 SMD with new STEP, DS, PROD_ID
    Update 1x08 SMD with new STEP, DS, PROD_ID
    Update 1x10 SMD with new STEP, DS, PROD_ID
    Update DCJ with new STEP
    Add datasheet to FPC FP
    Add datasheet to JST 1mm 3p FP
    Add datasheet to DCJ FP
    Add 1x06 Passthru FP
    Add 1x10 Passthru FP
    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
    [BG125-06-A-2-1-0420-N-C.step, BG125-06-A-2-1-0420-N-C.stp, BG125-08-A-2-1-0420-N-C.step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]
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2025-02-21 Add 3D Model and split ACS37800 fp
    - Generalize ACS37800 FP into SOICW16
    - Add solder lug footprint
    - Add SOICW16 3D Model
    [SO-16W_7.5x10.3mm_P1.27mm v1.step]
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2025-02-21 Correct SMD 2mm FPs to match parts in stock
2025-02-21 Rename 3D models. Fix Pin1RightDown name.
    [1x06_SMD_Pin1RightDown.step, 1x08_SMD_Pin1RightDown.step, 1x10_SMD_Pin1RightDown.step]
2025-02-21 Fix 3D model names
    [FPC_0.5mm-22-Vertical.STEP, JST_SMD_1.0mm-3_Vertical.STEP, Power_Jack_SMD.step]
2025-02-21 Add datasheets to connectors. Fix FPs with 'Down'.
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2025-02-25 Add rfid parts
    Add 1x5 and 1x9 PTH connectors.
    Add part outline for new module.
    [1x05_PTH_2.54mm_8.5mm.step, 1x09_PTH_2.54mm_8.5mm.step]
2025-03-05 Correct 3D model of bottom mount green LED
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2025-03-20 Add new 2x10 4UCon parts for GNSS Plug-In Modules
    [2x10_2.0mm_Header_SMD_Pegs-1.0mm_22817.stp, 2x10_2.0mm_Socket_SMD_Pegs-1.0mm_22815.stp]
2025-03-20 Update 2x10 2.0mm step files - add color, remove PnP caps
    [2x10_2.0mm_Header_SMD_Pegs-1.0mm_22817.step, 2x10_2.0mm_Header_SMD_Pegs-1.0mm_22817.stp, 2x10_2.0mm_Socket_SMD_Pegs-1.0mm_22815.step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]
2025-03-21 Add 3D model and extended version of MIMXRT1062
    [BGA_10x10mm_P0.65mm.step]
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2025-03-28 Add 74HC4066 QFN-14. Correct footprint for AP7361C
    [QFN-14_2.5x3mm_P0.5mm.step]
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2025-03-28 Separating out (and updating) 3dmodel file links
    -Separated out the step files for the FPC and the sensor itself in the "outline" footprint. This is nice so you can choose to click the "show" button and see each item individually.
    -This also updates the FPC portion of this footprint to use the latest version of the FPC with corrected coloring.
    [BMV080.step]
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2025-04-04 Added 3/9-pin versions, fixed color variation on faces
    [PinHeader_1x01_P2.54mm_Vertical.step, PinHeader_1x03_P2.54mm_Vertical.step, PinHeader_1x05_P2.54mm_Vertical.step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]
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2025-04-10 Add GNSS Flex Legend symbol and Template footprint
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2025-04-11 LED PTH footprint mods and 3d model
    -added fab outline of 5mm LED PTH (to help users avoid collisions when populated)
    -added/created 3d model
    [LED_5MM-RED.step, LED_5MM.FCStd, LED_PTH_5mm_Red.step]
2025-04-11 corrected pad names to match other LED symbols/fps
2025-04-11 copying in led symbol file from main branch
    -trying to avoid a rebase conflict
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2025-04-22 Correct pin number gremlin on 74HC4066
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2025-04-24 Fix LED merge
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2025-04-28 Fixes the pin name size so that it's visible
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2025-04-28 Fix Sym, FP, and models for black screw terminals
2025-05-01 Add HSTX BoB parts.
    Add 100mA charge pump.
    Add dual NMOS FET package and 3D model.
    Add 22-pin RA 0.5mm FPC connector and 3D model.
    Add HDMI-A connector.
    Add 4x220 ohm 0804 resistor array and 3D model.
    Add 4x10k ohm 1206 resistor array and 3D model.
    [FPC_0.5mm-22-RA.step, RES_0804_4_ARR.step, RES_1206_4_ARR.step]
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2025-05-21 Adds SHTC3 and STC31 symbols, footprints, and 3-D models
    [SHTC3.STEP, STC31.step]
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2025-06-11 Fix footprint and symbol name on 4x0603 resistor array
2025-06-11 Fix 4x0402 FP and symbol
    [R_Array_Convex_4x0402.step]
2025-06-11 Fix 22 pin FPC FP
    [FPC_0.5mm-22.step]
2025-06-11 Move LGA 3D file to standard ICs. Rename.
    [LGA-16_3x3x1mm.step, LIS3DH_LGA-16_3x3x1mm.step]
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2025-06-12 Fixes path to the footprint for the LIS3DH
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2025-08-19 Fix value on SMD battery
2025-08-19 Add DFN and Filter package and step. Add SAW filter and LNA.
    [DFN-6_1.5x1.9mm_P0.5mm.stp, Filter_1109-5_1.1x0.9mm.step]
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2025-08-27 Add 2x10_SMD_RA 3D model
    Also fix model path for corresponding footprint
    [2x10_SMD_RA.stp]
2025-08-28 Replace 3D model for RFCMF1220100M4T - see #211
    [CHIP_100M4T_WAL.step, RFCMF1220100M4T.stp]
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2025-08-29 Fix FPC connector name and FP
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2025-08-29 Fix 2x20 header pin order to zig-zag
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2025-09-10 Fix RFCMF1220100M4T symbol pin numbers
    Changing to the 'small' symbol revealed this error. See commit 1eb09a11334eea2e0cd8110439974932e5bae5d8
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2025-09-10 Add 'Septentrio' to FP and model names. Colorize 3D model.
    [Septentrio_mosaic-G5.step, Septentrio_mosaic-Rev5.step, Septentrio_mosaic-X5-Rev5.step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]
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2025-09-26 Resets branch and re-adds connector symbols and footprints
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2025-09-26 Adds 3d models for transformer, and 2x03 smd connector
    [2x03_2.0mm_SMD_Male.STEP, B1601S.STP]
2025-09-26 Change linked KiCad 3D models to local copies
    [D_SOD-123.step, LGA-8_3x5mm_P1.25mm.step, L_0805_2012Metric.step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]
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2025-09-26 Revert "Ethernet parts"
    [2x03_2.0mm_SMD_Male.STEP, Ethernet_Transformer_B1601S_SMD.step, RJ45_Ethernet_Mid_Mount_SMD.step]
2025-10-16 PCM updates : rename folders - step 1
    [1.5in OLED.step, 1x04_RA_SMD.step, 1x05_2.0mm.step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]
2025-10-16 PCM updates : rename folders - step 2
    [1.5in OLED.step, 1x04_RA_SMD.step, 1x05_2.0mm.step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]
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2025-11-25 Update 1x06 SMD Socket
    Update schematic symbol
    - Fix description to "female" pins
    - Update datasheet link
    - Update part number (for internal use)
    Add 3D model for footprint
    Links 3D model to the footprint of the schematic symbol
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2025-12-05 Fix PTH Test Point
    Update footprint
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2025-12-06 fix: unshrouded cortex debug connector footprint
    The SparkFun-Connector:Debug-Cortex-2x5_P1.127mm-SMD-Unshrouded is
    not correctly linked to the corresponding footprint.
2025-12-08 Fix ERC power warnings on symbols
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2025-12-14 fix: ws2812_5050 footprint
    The SparkFun-LED:WS2812B_5050 does not link to the correct footprint.
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2025-12-17 Fix 2200pF capacitor part number and datasheet
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2026-01-23 Fix stacked power pins
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2026-02-05 Fix symbols using SOT-363 after footprint rename
    Fixes #256
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2026-03-30 Tighten courtyard on locking JSTs
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2026-05-21 Add missing 3D model to 0806 coil footprint
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2026-08-07 Fix Teensy 4.1 Shield Symbol
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2026-09-08 Fix LBEE5KL1YN
    Change 3D model from .STEP to .step to match the actual file name
    Correct SR_VLX pin to be of type Power ouput
    Change component type to SMD (otherwise it's listed as a virtual model in the 3D viewer)
    Increase pin 1 indicator size
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2026-09-09 Fix TFBGA-24 footprint to be perfectly on grid
2026-09-09 Add LSM6DSV16X
    Existing SKU, just new KiCad symbol
    Also fix footprint Component type to be SMD so it renders correctly in 3D Viewer
2026-09-09 Fix Inductor_7.3x6.6mm footprint Component type to be SMD so it renders correctly in 3D Viewer
2026-09-09 Fix PowerVFDFN-13 footprint Component type to be SMD so it renders correctly in 3D Viewer
2026-09-09 Fix crystal symbols and footprints
    All 4-pad crystal symbols use GND pins now
    Update 2.0x1.6mm footprint to change NC pins to GND pins
    Add crystal icon to all crystal footprints
    Add PROD_ID to 27MHz crystal
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2026-09-17 Fix pin one indicator size.
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2026-09-24 Updated Teensy symbol to fix pin error
2026-09-24 Teensy 4.1 shield updates
    Remove space from footprint name
    Rename 3.3V pin to 3V3 to avoid automatic connections to 3.3V power symbols
    Change all power pins to power ouptut types
    Add double header symbol and footprint
2026-10-20 Update JST_1x06_P1.25mm_Locking_Horizontal_SMD.kicad_mod - fix segmented courtyard
2026-10-20 Update PowerVFDFN-13.kicad_mod - override pad clearance to 0.15mm
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2026-10-29 Fix DE9 footprint and symbol
    Fixes reversed pin layout
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2026-11-11 Add Conn_01x18_FPC_P0.5mm_Horizontal_BottomContact_Hinge_ReverseNumbering. Reference correct 2x13 footprint
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

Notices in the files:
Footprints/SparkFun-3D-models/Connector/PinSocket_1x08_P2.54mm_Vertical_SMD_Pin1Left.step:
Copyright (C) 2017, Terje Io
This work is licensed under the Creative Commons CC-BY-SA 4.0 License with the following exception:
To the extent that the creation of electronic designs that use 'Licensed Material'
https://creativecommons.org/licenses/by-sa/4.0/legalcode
